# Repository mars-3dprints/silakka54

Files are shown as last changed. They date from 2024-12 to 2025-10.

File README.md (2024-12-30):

# Silakka54

Silakka54 is a RP2040 Zero based 54-key column staggered split keyboard. PCB uses hotswap sockets. Design is inspired from REVIUNG41 and Corne keyboards.

PCB is designed for MX style key switches. Current top plate only supports MX style switches. 5-pin switches are supported. I recommend using Vial firmware.

**For more information visit https://squalius-cephalus.github.io/silakka54/**

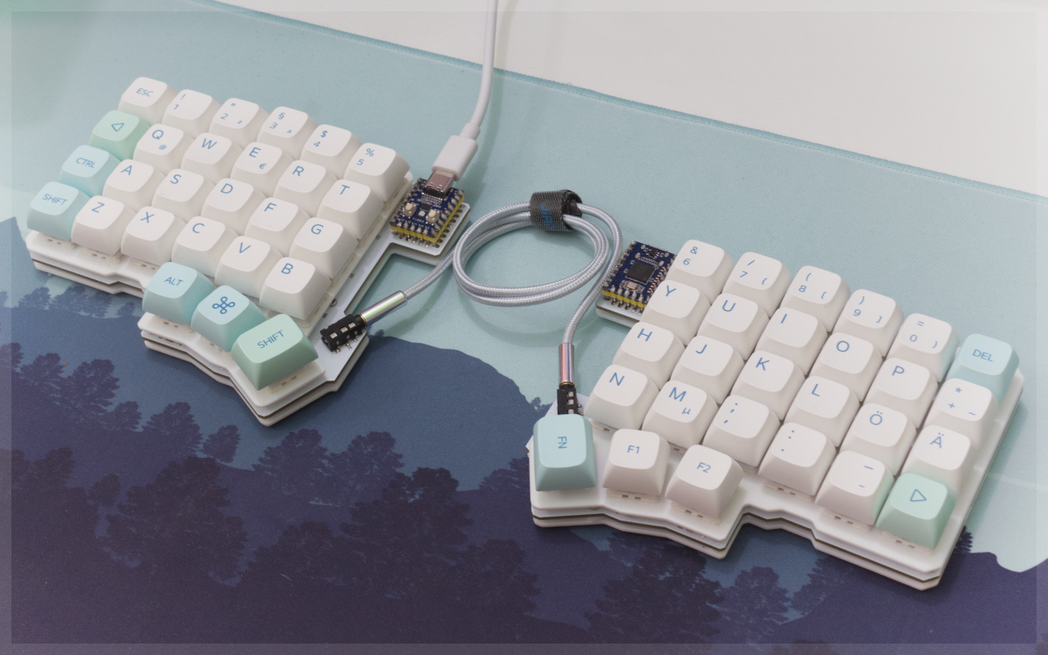
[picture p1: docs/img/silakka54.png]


PCB design uses footprints from [ScottoKeebs](https://github.com/joe-scotto/scottokeebs/tree/main/Extras/ScottoKicad "ScottoKeebs") and [kbd library.](https://github.com/foostan/kbd "kbd library.")

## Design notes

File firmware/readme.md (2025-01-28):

# Silakka54

Silakka54

Silakka54 is a RP2040 Zero based 54-key column staggered split keyboard. PCB uses hotswap sockets. Design is inspired from REVIUNG41 and Corne keyboards.

* Keyboard Maintainer: [Squalius-cephalus](https://github.com/Squalius-cephalus)
* Hardware Supported: Silakka54 PCB
* Hardware Availability: https://github.com/Squalius-cephalus/silakka54

Make example for this keyboard (after setting up your vial build environment):

    make silakka54:vial

Flashing example for this keyboard:

    make silakka54:vial:flash

## Bootloader

Enter the bootloader in 2 ways:

* **Physical boot button**: Hold BOOT button down and connect MCU to the PC
* **Keycode in layout**: Press the key mapped to `QK_BOOT` if it is available

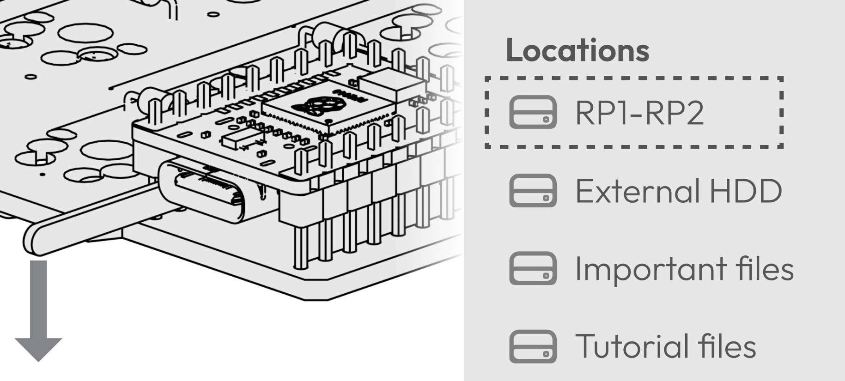
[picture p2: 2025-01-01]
docs/img/firmware_Upload.png

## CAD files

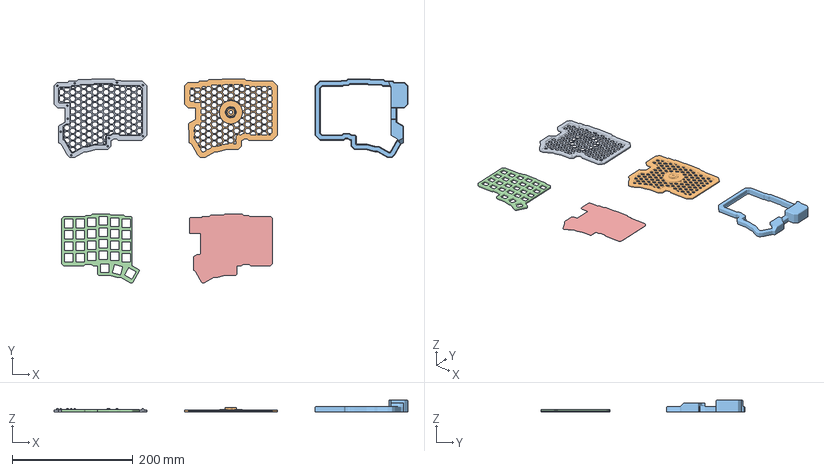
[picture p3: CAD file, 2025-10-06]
case/3MF/complete.3mf
586.1 x 338.3 x 20.0 mm
base.stl
stand-base.stl
cover-merged.stl
spacer.stl
plate.stl

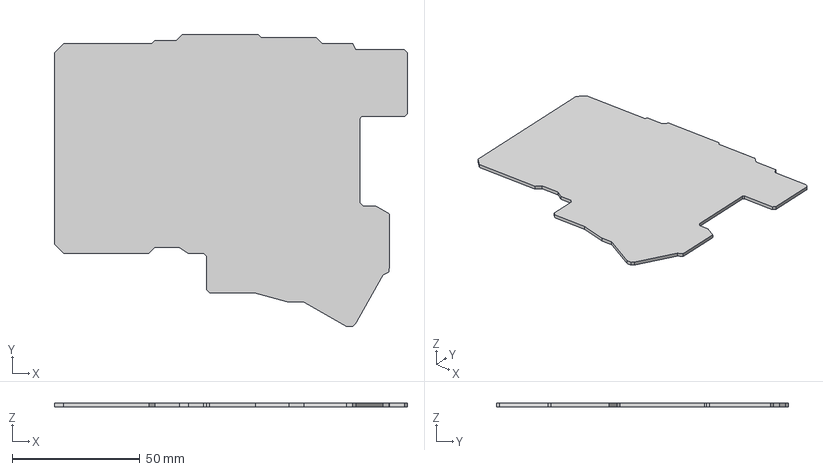
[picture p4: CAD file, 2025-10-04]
case/STEP/plate.step
138.1 x 114.3 x 1.60 mm

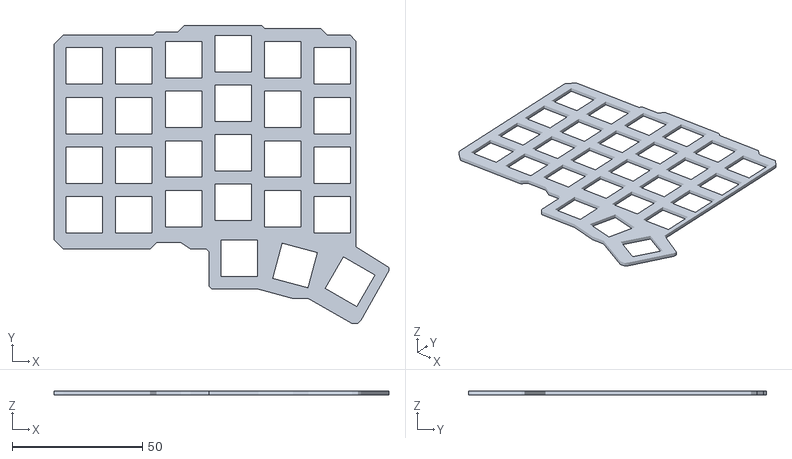
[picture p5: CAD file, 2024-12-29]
stl/Top_Plate_left.stl
128.6 x 114.3 x 1.60

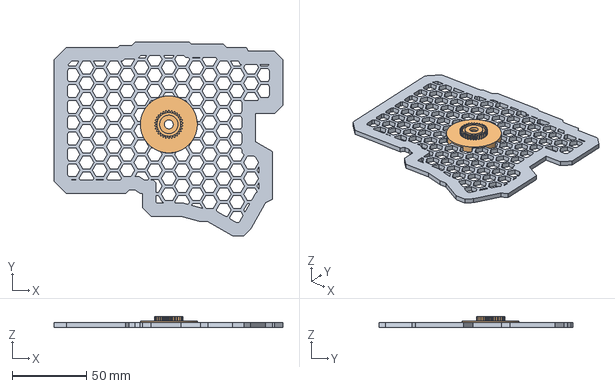
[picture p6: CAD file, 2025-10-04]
case/STEP/magsafe_stand_base.step
154.1 x 130.3 x 7.20 mm

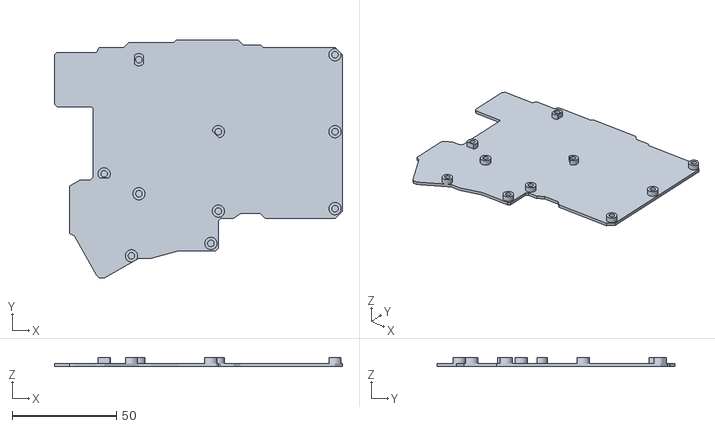
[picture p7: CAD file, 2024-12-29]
stl/Bottom_plate_right.stl
138.1 x 114.3 x 4.48

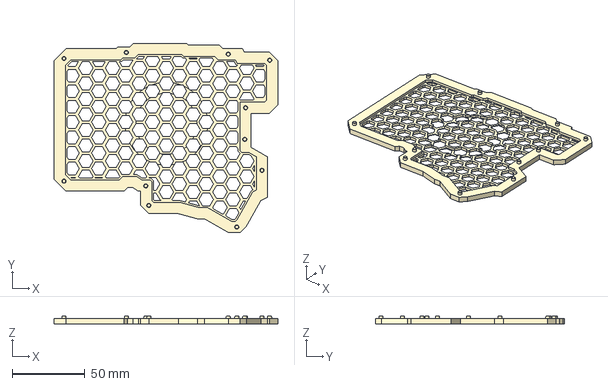
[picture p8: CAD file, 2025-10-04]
case/STEP/base.step
154.1 x 130.3 x 5.75 mm

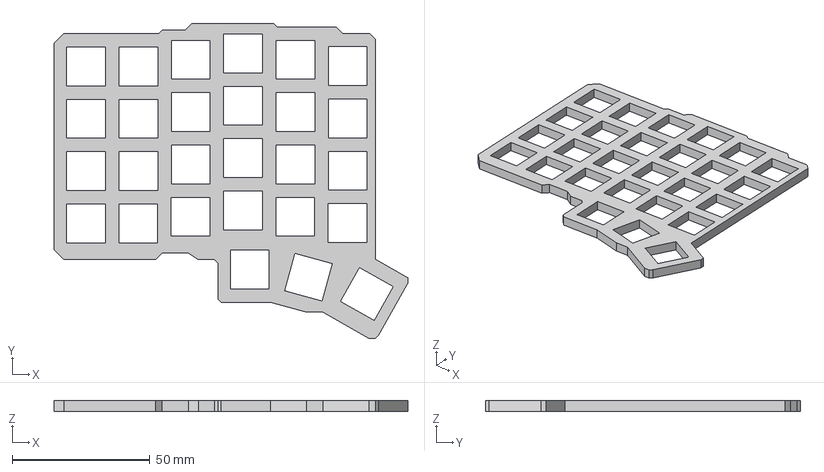
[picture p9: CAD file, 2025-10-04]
case/STEP/keycap_spacer.step
128.5 x 114.3 x 4.00 mm

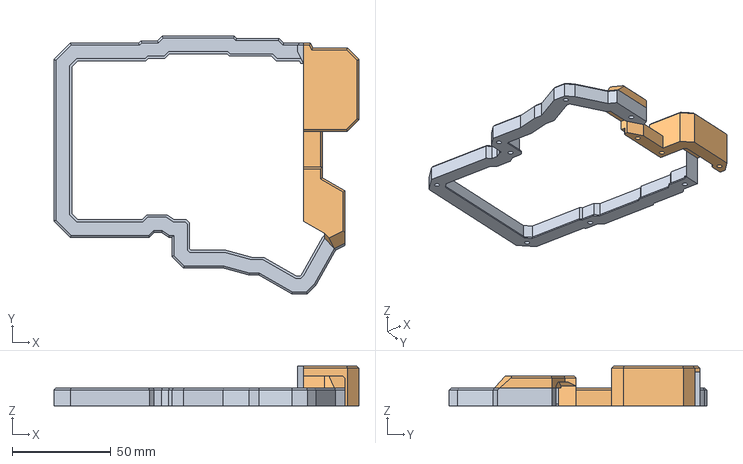
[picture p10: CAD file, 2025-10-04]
case/STEP/top_frame.step
154.1 x 130.3 x 20.0 mm

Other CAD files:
step/pcb.step
stl/Bottom_plate_left.stl
stl/Top_Plate_right.stl
case/STL/base.stl
case/STL/keycap_spacer.stl
case/STL/magsafe_stand_base.stl
case/STL/plate.stl
case/STL/top_frame.stl

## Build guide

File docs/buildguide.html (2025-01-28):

About Build Guide Firmware Troubleshooting

# Build Guide

### Bill of materials

- 54 x MX compatible key switches
- 54 x Kailh Hotswap Sockets
- 54 x 1N4148 Diodes
- 52 x 1u keycaps
- 2 x 1.5u keycap
- 2 x RP2040 Zero
- 2 x PJ320D audio sockets
- 1 x TRRS audio cable
- 20 x M2 Heat set inserts, length 2mm(OD3.2mm)
- 20 x M2 bolts, length 4mm
- 2 x PCB (https://github.com/Squalius-cephalus/silakka54/tree/main/gerber)
- 2 x Bottom plate (https://github.com/Squalius-cephalus/silakka54/tree/main/stl)
- 2 x Top plate (https://github.com/Squalius-cephalus/silakka54/tree/main/stl)

Most of the components can be found on Aliexpress. PCB can be bought from a PCB manufacturer, usually there is a minimum order of 5 pcs. This is fine, because you can use the same PCB design on both sides of the keyboard.

PCB thickness should be 1.6mm, 2 layers and lead free finish. You can find gerber (https://github.com/Squalius-cephalus/silakka54/tree/main/gerber) files from the repository.

Top and bottom plates can be printed from PLA. No supports is required.

Install firmware files to the RP2040 Zero microcontrollers. Hold down the BOOT button and connect microcontroller to the computer.

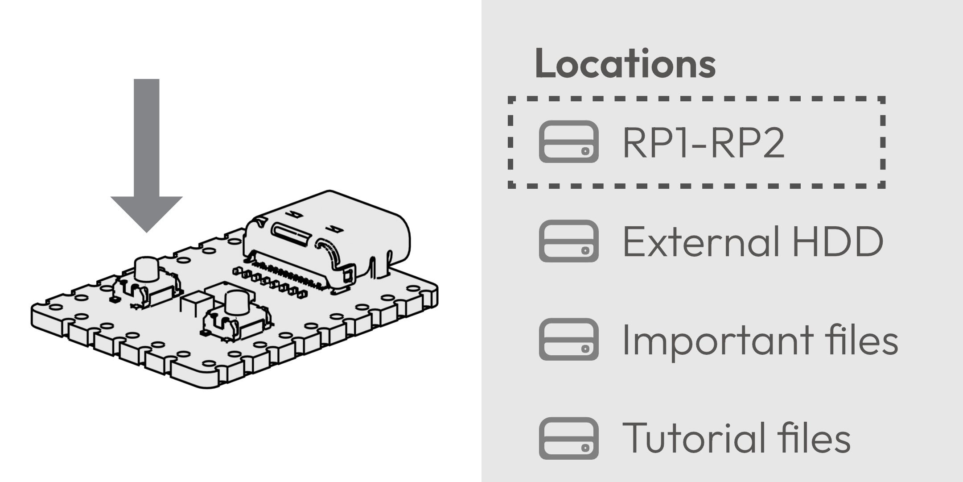
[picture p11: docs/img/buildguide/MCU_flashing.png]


It should appear as USB mass storage. Drag and drop the silakka54_vial.uf2 (https://github.com/Squalius-cephalus/silakka54/releases) file, and the drive should automatically disconnect.

If you can't get the drive to show up, try a different USB cable, connect directly to the computer and make sure that USB cable can carry data. After you installed firmware to both microcontrollers, you can start the soldering process.

Solder pin headers to the microcontroller. Second microcontroller needs to be rotated, so the buttons face down.

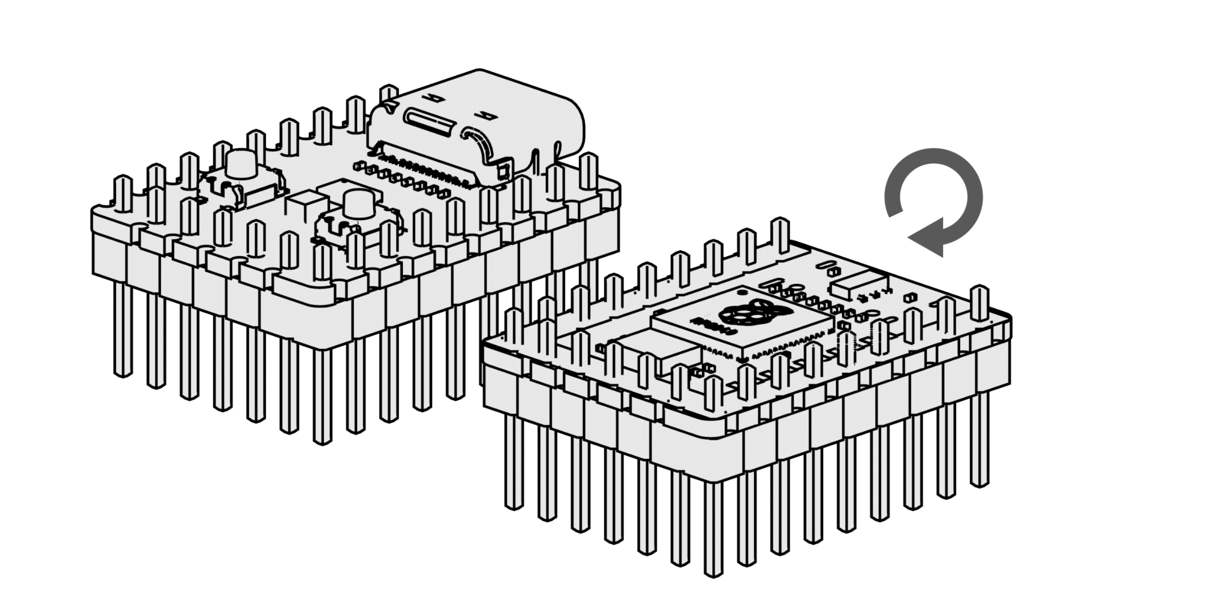
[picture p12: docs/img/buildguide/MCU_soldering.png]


Solder hotswap sockets to both PCBs.

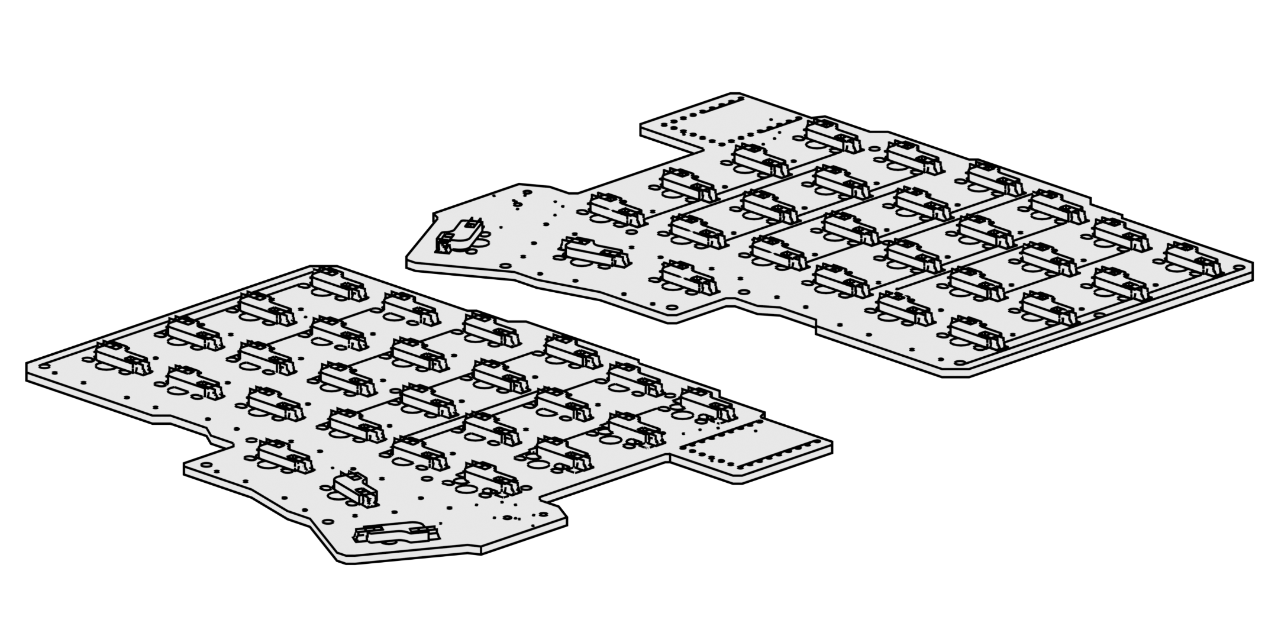
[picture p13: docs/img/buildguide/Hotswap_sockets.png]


Solder diodes, make sure to install those the right way round. Solder both microcontrollers. Don't solder those too close to the PCB, leave a two-millimeter gap, the legs of the pin header should be long enough.

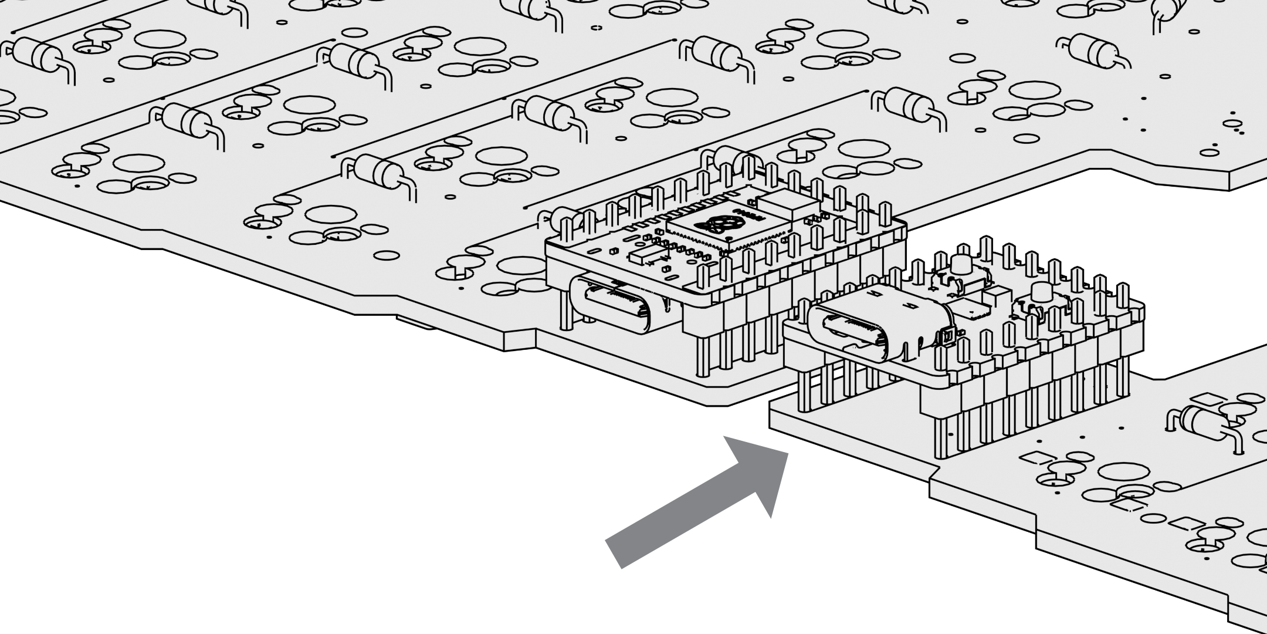
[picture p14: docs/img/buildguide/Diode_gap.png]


There is no RESET pin on the Zero, so you need to have access to RESET and BOOT buttons if you want to change/upload the firmware.

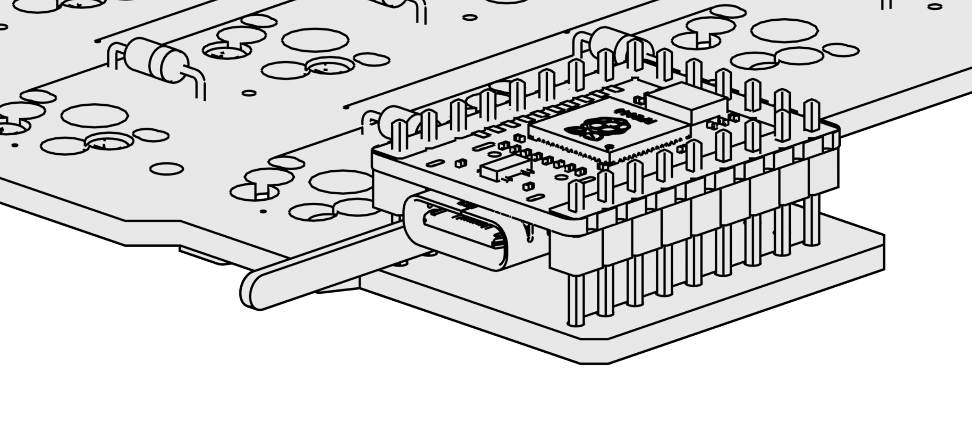
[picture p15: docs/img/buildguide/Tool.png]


Solder the audio connectors, those should be on top of the board.

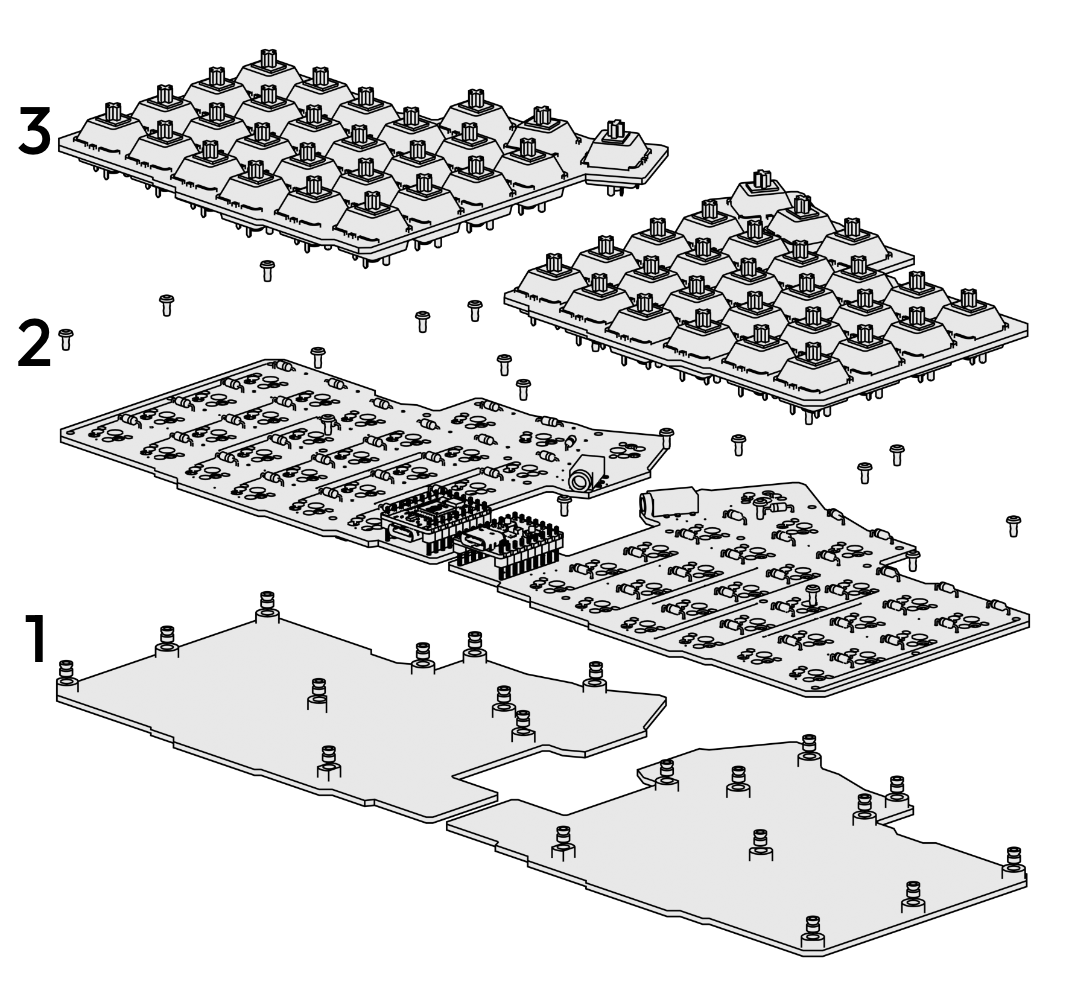
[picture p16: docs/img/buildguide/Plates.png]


Insert heat set inserts to the bottom plates using soldering iron. Temperature should be around 220°C. Fasten the PCBs to the base with bolts, insert key switches to the top plate and push the plate to the PCB.

Don't bend any pins! Plates should connect without too much force.

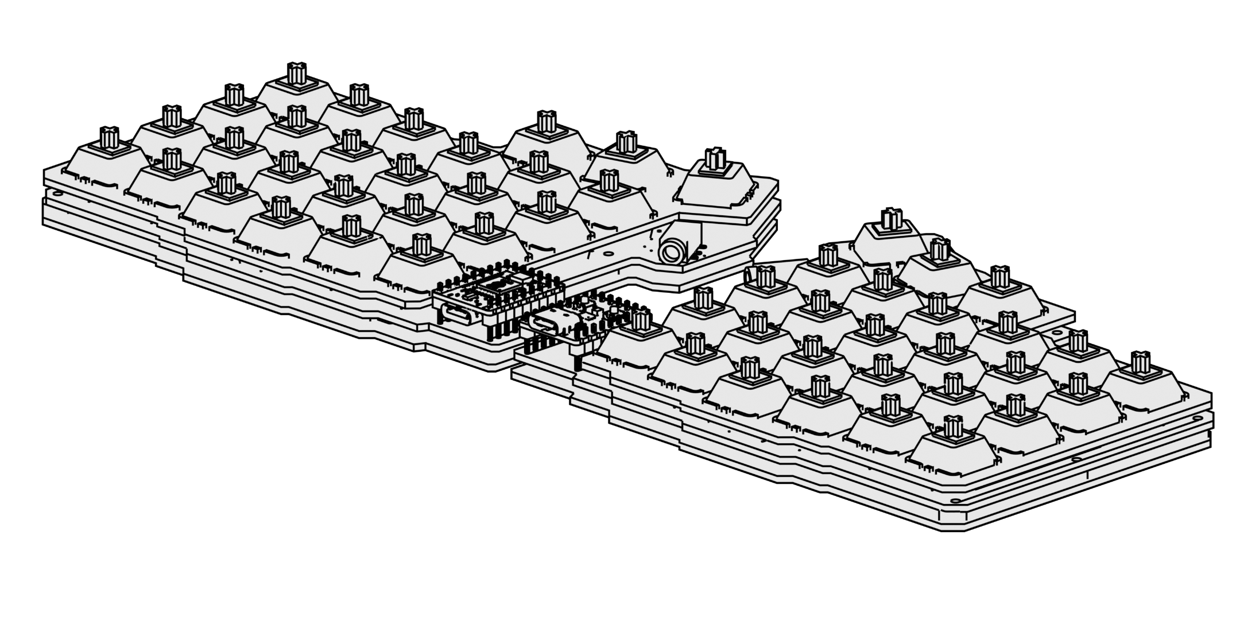
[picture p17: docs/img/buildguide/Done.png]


Add keycaps, connect both halves with TRRS cable and connect the left side microcontroller to the computer.

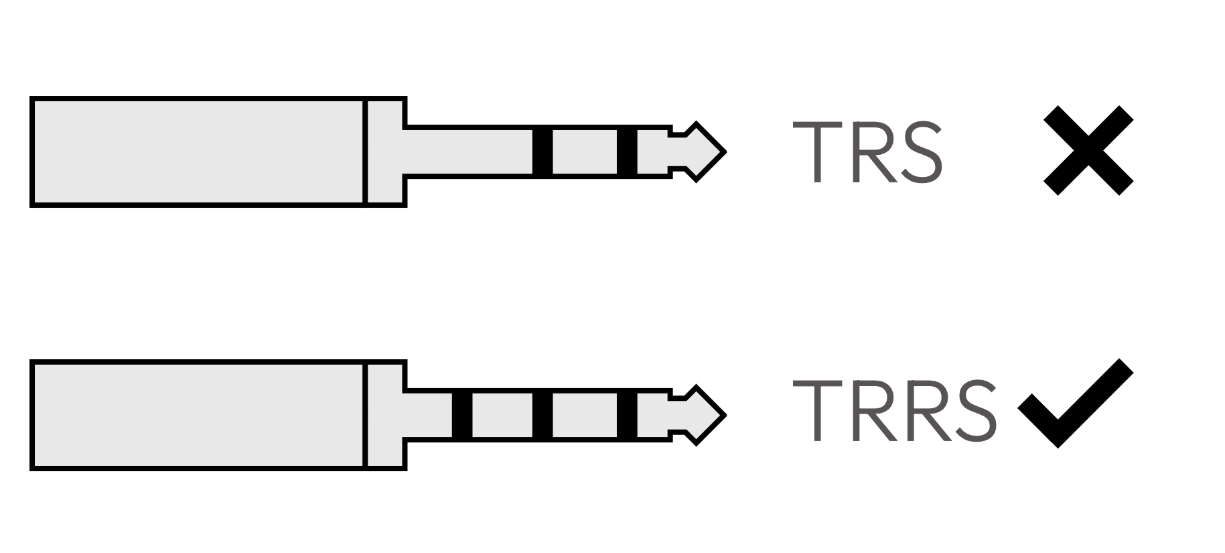
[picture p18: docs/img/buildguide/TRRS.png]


You need to use TRRS cable, TRS cable is missing one pin!

Test functionality of the keyboard using Vial (https://get.vial.today/), with matrix tester you can test easily every key even if the key is mapped to nothing.

Silakka54 keyboard is maintained by Squalius-cephalus (https://github.com/Squalius-cephalus)

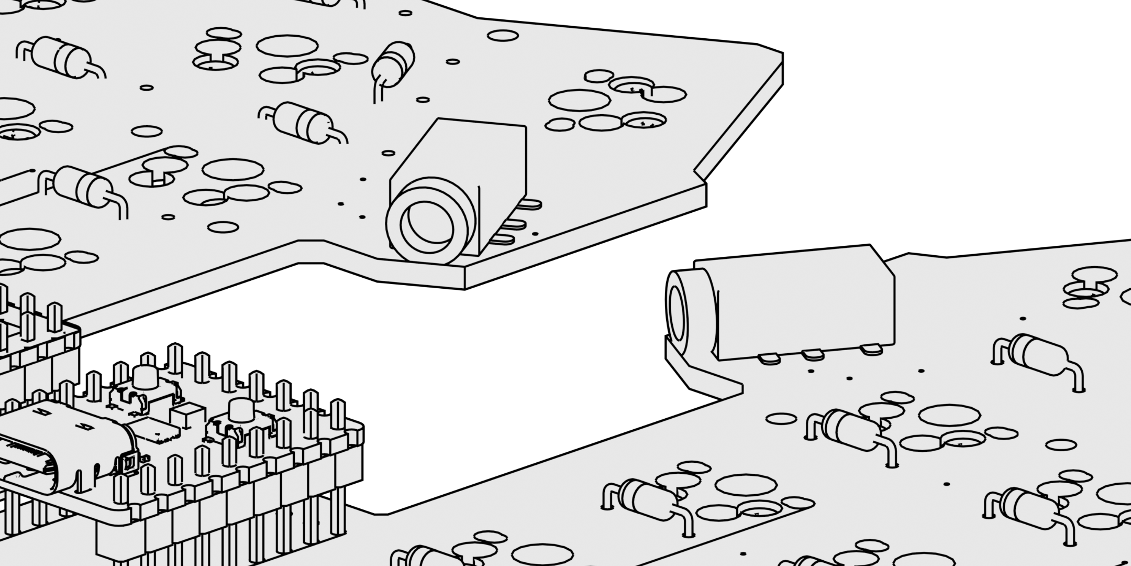
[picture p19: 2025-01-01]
docs/img/buildguide/Audio_jacks.png

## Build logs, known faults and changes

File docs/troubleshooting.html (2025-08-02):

About Build Guide Firmware Troubleshooting

# Troubleshooting

Here is a list of the most common problems you may encounter when using silakka54 after assembling.

### Random keys do not work after assembling

Check that there are no cold solder joints on the PCBs. Make sure that the diodes are positioned correctly. One reason may also be a twisted pin in the switch. Remove the switch and make sure the pins are straight.

### The keyboard works but all keys are flipped

Connect the USB cable to left side, if it's connected to right side, firmware needs to be modified.

### The right side of the keyboard does nothing, even when the audio cable is connected.

If you have purchased a pre-built silakka54, they often have very tight TRRS connectors. Ensure that the connector is fully inserted!

Make sure it's a TRRS cable and not a TRS. Many cheap cables are just TRS cables.



### I tried googling "silakka", but all I get in the image search are pictures of fish

🐟!

Silakka54 keyboard is maintained by Squalius-cephalus (https://github.com/Squalius-cephalus)

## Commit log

2024-12-29 New website, new firmware files, STL files etc
    New website with build guide, fixed the STL files, new firmware files and some typos fixed.
    [Bottom_plate_left.stl, Bottom_plate_right.stl, Top_Plate_left.stl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]
2025-01-08 feat: Add PCB as step file
    Makes it convenient to design cases
    [pcb.step]
2025-01-28 Updated the firmware, added more info for the website
    [silakka54_stl.blend]
2025-04-15 Added STL and STEP files for 3D printable case
    [base.step, base.stl, base_clean.step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]
2025-08-02 Added information about unused GPIO pins and the "wireless" silakka54.
2025-09-18 Enable vial 0.7.4 new buttons - CAPS_WORD and LAYER_LOCK by default. No visible downsides but will allow users to map new buttons without compilation of firmware.
2025-10-04 Replace STEP and STL files
    [base.step, base.stl, base_clean.step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]
2025-10-06 Add 3MF file for Bambulab slicer
    [complete.3mf]
